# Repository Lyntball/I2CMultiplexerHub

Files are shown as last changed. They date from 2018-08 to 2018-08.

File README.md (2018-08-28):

# I2CMultiplexerHub
I2C Multiplexer Hub Sor Sensor Reading and Device Control

This is a hub for reading data from sensors with the same address or controlling devices with the same address. The inital creation was to read multiple sensors with the same I2C address. After exploring the possibilities, I was able to use the same structure as TCP/IP to use the multiplexer as a 'sub-net' of sorts

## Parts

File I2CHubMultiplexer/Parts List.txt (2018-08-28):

Per PCB:
TCA9548A (TSSOP24) - 1  $1.51/Each = $1.51
RJ45 Circuit Board Mount - 10  $1.07/Each = $10.70
LED-Green 0603SMD - 11  $0.14/Each = $1.54
150 Ohm Resistor 0603SMD - 11  $0.06/Each = $0.66
2.1 Circuit Board Mount Barrel Jack - 1  $0.95/Each = $0.95
10 KOhm Resistor 0603SMD - 6   $0.10/Each = $0.60
10 uF Capacitor - 1   $0.14/Each = $0.14
3.3 Voltage Regulator (SOT-223) - 10   $0.33/Each = $3.30
PCB - 7.824 = $7.82

$27.20 Total

5
50
55
55
5
30
5
50

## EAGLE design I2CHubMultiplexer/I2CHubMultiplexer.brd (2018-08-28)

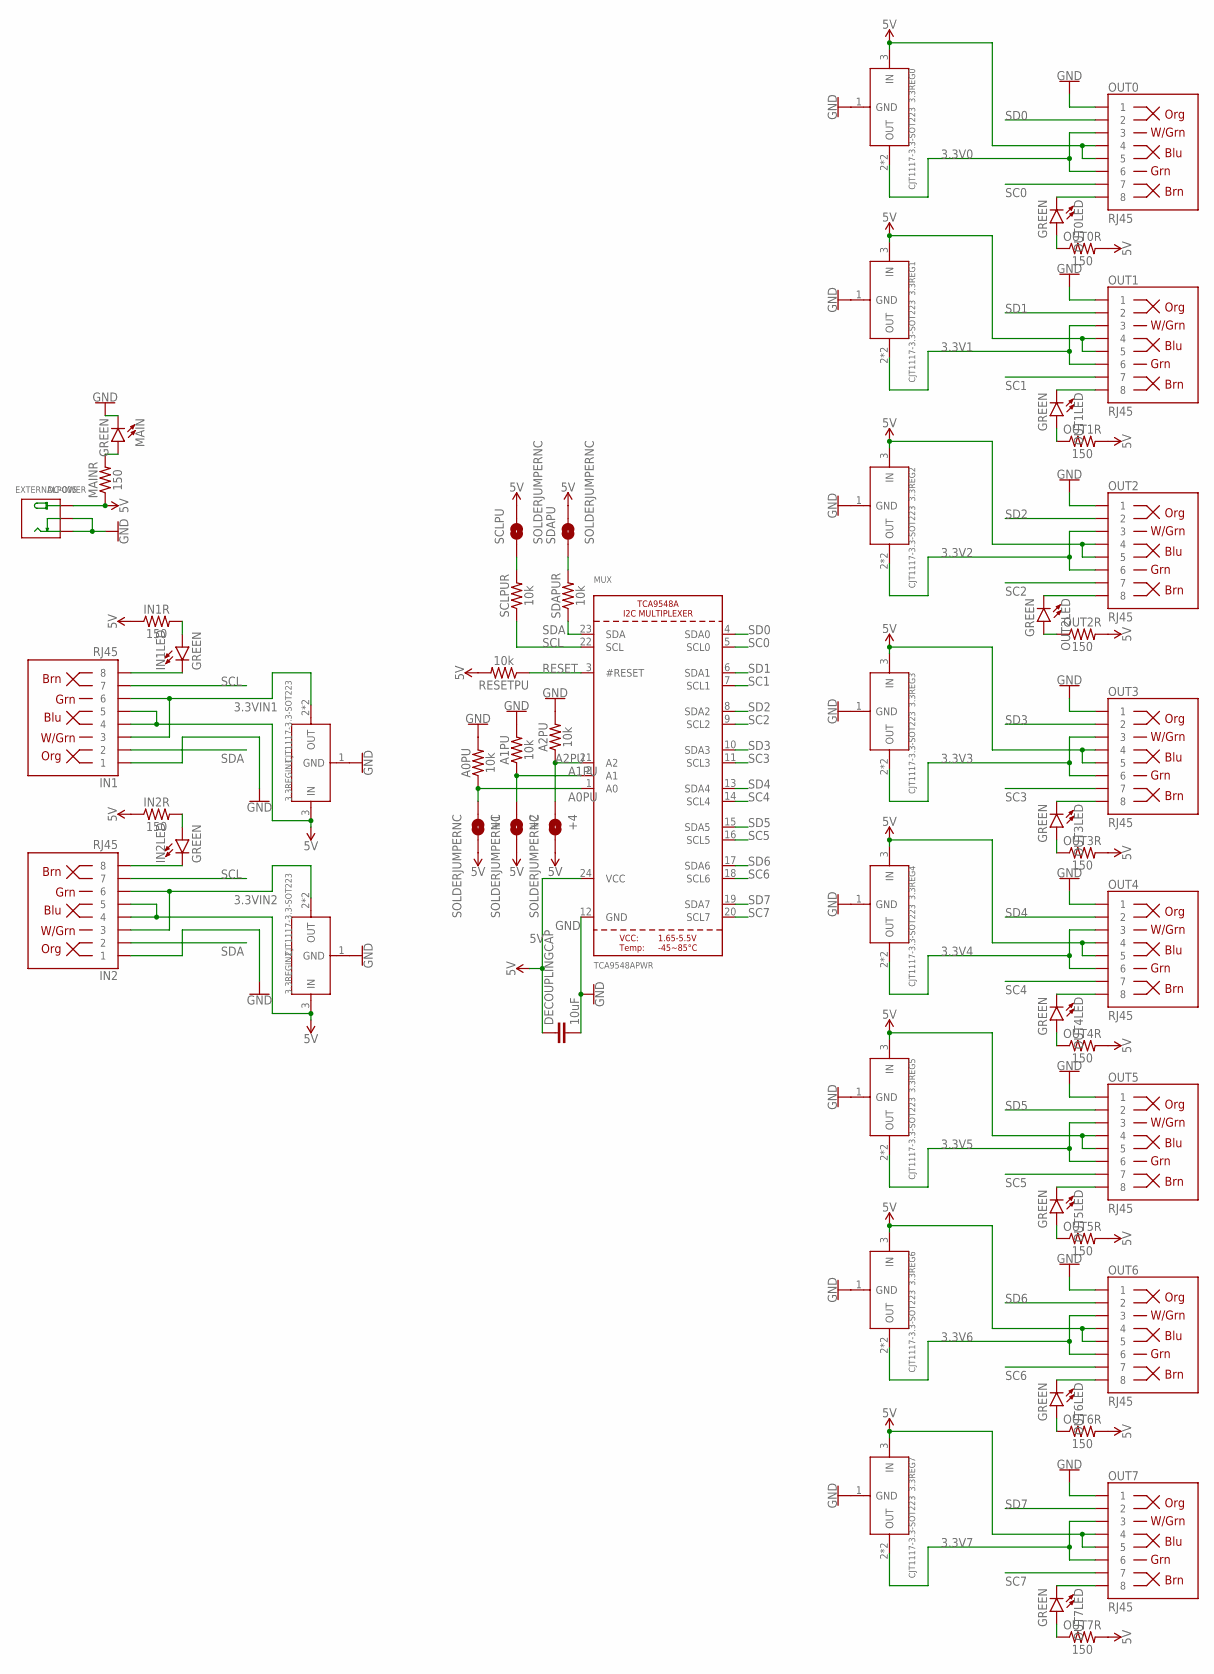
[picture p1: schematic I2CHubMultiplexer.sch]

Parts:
3.3REG0, 3.3REG1, 3.3REG2, 3.3REG3, 3.3REG4, 3.3REG5, 3.3REG6, 3.3REG7, 3.3REGIN1, 3.3REGIN2: CJT1117-3.3-SOT223; SOT-223
+1, +2, +4: SOLDERJUMPERNC; SJ_2S
A0PU, A1PU, A2PU: 10k; 0603
DECOUPLINGCAP: 10uF; 0603
EXTERNALPOWER: DC-005; DCJ3P-14.2X11.0X9.0MM
IN1, IN2: RJ45; RJ45-8
IN1LED, IN2LED: GREEN; LED-0603
IN1R, IN2R: 150; 0603
MAIN: GREEN; LED-0603
MAINR: 150; 0603
MUX: TCA9548APWR; TSSOP24
OUT0, OUT1, OUT2, OUT3, OUT4, OUT5, OUT6, OUT7: RJ45; RJ45-8
OUT0LED, OUT1LED, OUT2LED, OUT3LED, OUT4LED, OUT5LED, OUT6LED, OUT7LED: GREEN; LED-0603
OUT0R, OUT1R, OUT2R, OUT3R, OUT4R, OUT5R, OUT6R, OUT7R: 150; 0603
RESETPU: 10k; 0603
SCLPU: SOLDERJUMPERNC; SJ_2S
SCLPUR: 10k; 0603
SDAPU: SOLDERJUMPERNC; SJ_2S
SDAPUR: 10k; 0603

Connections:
3.3V0: 3.3REG0.2 (OUT), 3.3REG0.TER (OUT), OUT0.3, OUT0.6
3.3V1: 3.3REG1.2 (OUT), 3.3REG1.TER (OUT), OUT1.3, OUT1.6
3.3V2: 3.3REG2.2 (OUT), 3.3REG2.TER (OUT), OUT2.3, OUT2.6
3.3V3: 3.3REG3.2 (OUT), 3.3REG3.TER (OUT), OUT3.3, OUT3.6
3.3V4: 3.3REG4.2 (OUT), 3.3REG4.TER (OUT), OUT4.3, OUT4.6
3.3V5: 3.3REG5.2 (OUT), 3.3REG5.TER (OUT), OUT5.3, OUT5.6
3.3V6: 3.3REG6.2 (OUT), 3.3REG6.TER (OUT), OUT6.3, OUT6.6
3.3V7: 3.3REG7.2 (OUT), 3.3REG7.TER (OUT), OUT7.3, OUT7.6
3.3VIN1: 3.3REGIN1.2 (OUT), 3.3REGIN1.TER (OUT), IN1.3, IN1.6
3.3VIN2: 3.3REGIN2.2 (OUT), 3.3REGIN2.TER (OUT), IN2.3, IN2.6
5V: 3.3REG0.3 (IN), 3.3REG1.3 (IN), 3.3REG2.3 (IN), 3.3REG3.3 (IN), 3.3REG4.3 (IN), 3.3REG5.3 (IN), 3.3REG6.3 (IN), 3.3REG7.3 (IN), 3.3REGIN1.3 (IN), 3.3REGIN2.3 (IN), +1.2, +2.2, +4.2, DECOUPLINGCAP.1, EXTERNALPOWER.+, IN1.4, IN1.5, IN1R.1, IN2.4, IN2.5, IN2R.1, MAINR.1, MUX.24 (VCC), OUT0.4, OUT0.5, OUT0R.2, OUT1.4, OUT1.5, OUT1R.2, OUT2.4, OUT2.5, OUT2R.2, OUT3.4, OUT3.5, OUT3R.2, OUT4.4, OUT4.5, OUT4R.2, OUT5.4, OUT5.5, OUT5R.2, OUT6.4, OUT6.5, OUT6R.2, OUT7.4, OUT7.5, OUT7R.2, RESETPU.2, SCLPU.2, SDAPU.2
A0PU: +1.1, A0PU.1, MUX.1 (A0)
A1PU: +2.1, A1PU.1, MUX.2 (A1)
A2PU: +4.1, A2PU.1, MUX.21 (A2)
GND: 3.3REG0.1 (GND), 3.3REG1.1 (GND), 3.3REG2.1 (GND), 3.3REG3.1 (GND), 3.3REG4.1 (GND), 3.3REG5.1 (GND), 3.3REG6.1 (GND), 3.3REG7.1 (GND), 3.3REGIN1.1 (GND), 3.3REGIN2.1 (GND), A0PU.2, A1PU.2, A2PU.2, DECOUPLINGCAP.2, EXTERNALPOWER.-1 (-), EXTERNALPOWER.-2 (CDN), IN1.1, IN2.1, MAIN.C, MUX.12 (GND), OUT0.1, OUT1.1, OUT2.1, OUT3.1, OUT4.1, OUT5.1, OUT6.1, OUT7.1
IN1LEDR: IN1LED.A, IN1R.2
IN2LEDR: IN2LED.A, IN2R.2
MAINLEDR: MAIN.A, MAINR.2
OU1LEDR: OUT1LED.A, OUT1R.1
OUT0LEDR: OUT0LED.A, OUT0R.1
OUT2LEDR: OUT2LED.A, OUT2R.1
OUT3LEDR: OUT3LED.A, OUT3R.1
OUT4LEDR: OUT4LED.A, OUT4R.1
OUT5LEDR: OUT5LED.A, OUT5R.1
OUT6LEDR: OUT6LED.A, OUT6R.1
OUT7LEDR: OUT7LED.A, OUT7R.1
RESET: MUX.3 (#RESET), RESETPU.1
RETRUNGNDIN1: IN1.8, IN1LED.C
RETURNGNDIN2: IN2.8, IN2LED.C
RETURNGNDOUT1: OUT1.8, OUT1LED.C
RETURNGNDOUT2: OUT2.8, OUT2LED.C
RETURNGNDOUT3: OUT3.8, OUT3LED.C
RETURNGNDOUT4: OUT4.8, OUT4LED.C
RETURNGNDOUT5: OUT5.8, OUT5LED.C
RETURNGNDOUT6: OUT6.8, OUT6LED.C
RETURNGNDOUT7: OUT7.8, OUT7LED.C
RETURNGRNDOUT0: OUT0.8, OUT0LED.C
SC0: MUX.5 (SCL0), OUT0.7
SC1: MUX.7 (SCL1), OUT1.7
SC2: MUX.9 (SCL2), OUT2.7
SC3: MUX.11 (SCL3), OUT3.7
SC4: MUX.14 (SCL4), OUT4.7
SC5: MUX.16 (SCL5), OUT5.7
SC6: MUX.18 (SCL6), OUT6.7
SC7: MUX.20 (SCL7), OUT7.7
SCL: IN1.7, IN2.7, MUX.22 (SCL), SCLPUR.1
SCLPU: SCLPU.1, SCLPUR.2
SD0: MUX.4 (SDA0), OUT0.2
SD1: MUX.6 (SDA1), OUT1.2
SD2: MUX.8 (SDA2), OUT2.2
SD3: MUX.10 (SDA3), OUT3.2
SD4: MUX.13 (SDA4), OUT4.2
SD5: MUX.15 (SDA5), OUT5.2
SD6: MUX.17 (SDA6), OUT6.2
SD7: MUX.19 (SDA7), OUT7.2
SDA: IN1.2, IN2.2, MUX.23 (SDA), SDAPUR.1
SDAPU: SDAPU.1, SDAPUR.2

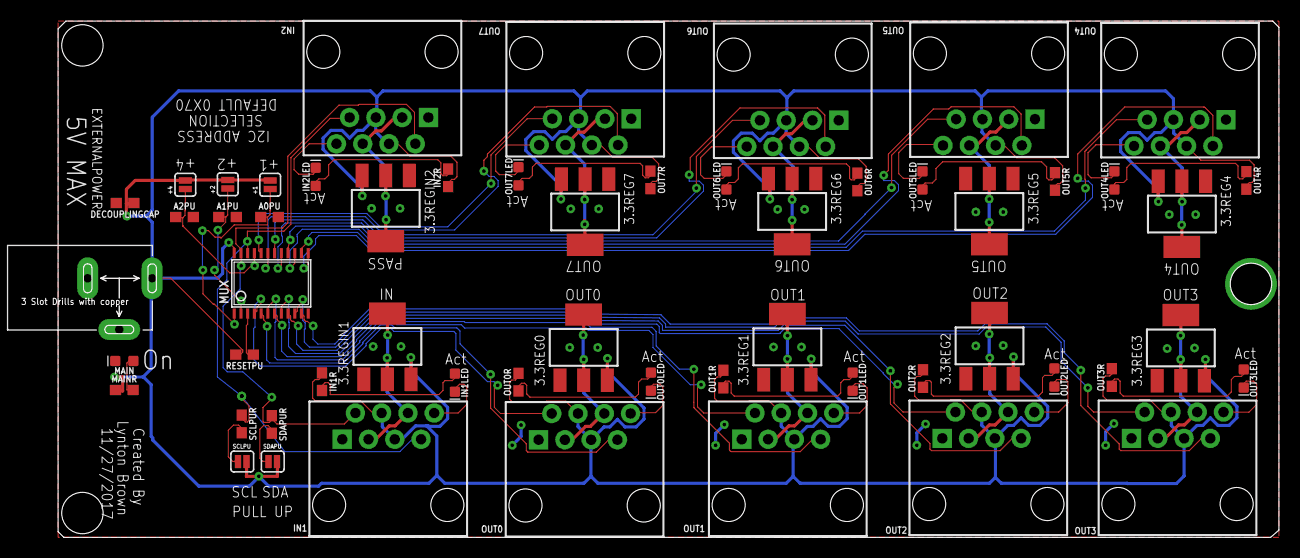
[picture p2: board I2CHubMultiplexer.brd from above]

Board: 2 copper layers, 118.0 x 49.9 mm, 56 parts (0 on the bottom side), 57 nets.

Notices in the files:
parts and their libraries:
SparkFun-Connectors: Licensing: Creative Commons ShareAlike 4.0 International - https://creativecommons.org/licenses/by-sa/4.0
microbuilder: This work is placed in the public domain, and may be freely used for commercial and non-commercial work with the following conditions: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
